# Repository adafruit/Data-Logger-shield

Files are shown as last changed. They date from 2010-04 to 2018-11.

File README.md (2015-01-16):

Adafruit Data Logger Shield PCB
===============================

PCB files for Adafruit's Data Logger Shield for Arduino

For more details, check out the product page at

-----> https://www.adafruit.com/product/1141

Adafruit invests time and resources providing this open source design, 
please support Adafruit and open-source hardware by purchasing 
products from Adafruit!

Designed by Adafruit Industries.  
Creative Commons Attribution, Share-Alike license, check license.txt for more information
All text above must be included in any redistribution

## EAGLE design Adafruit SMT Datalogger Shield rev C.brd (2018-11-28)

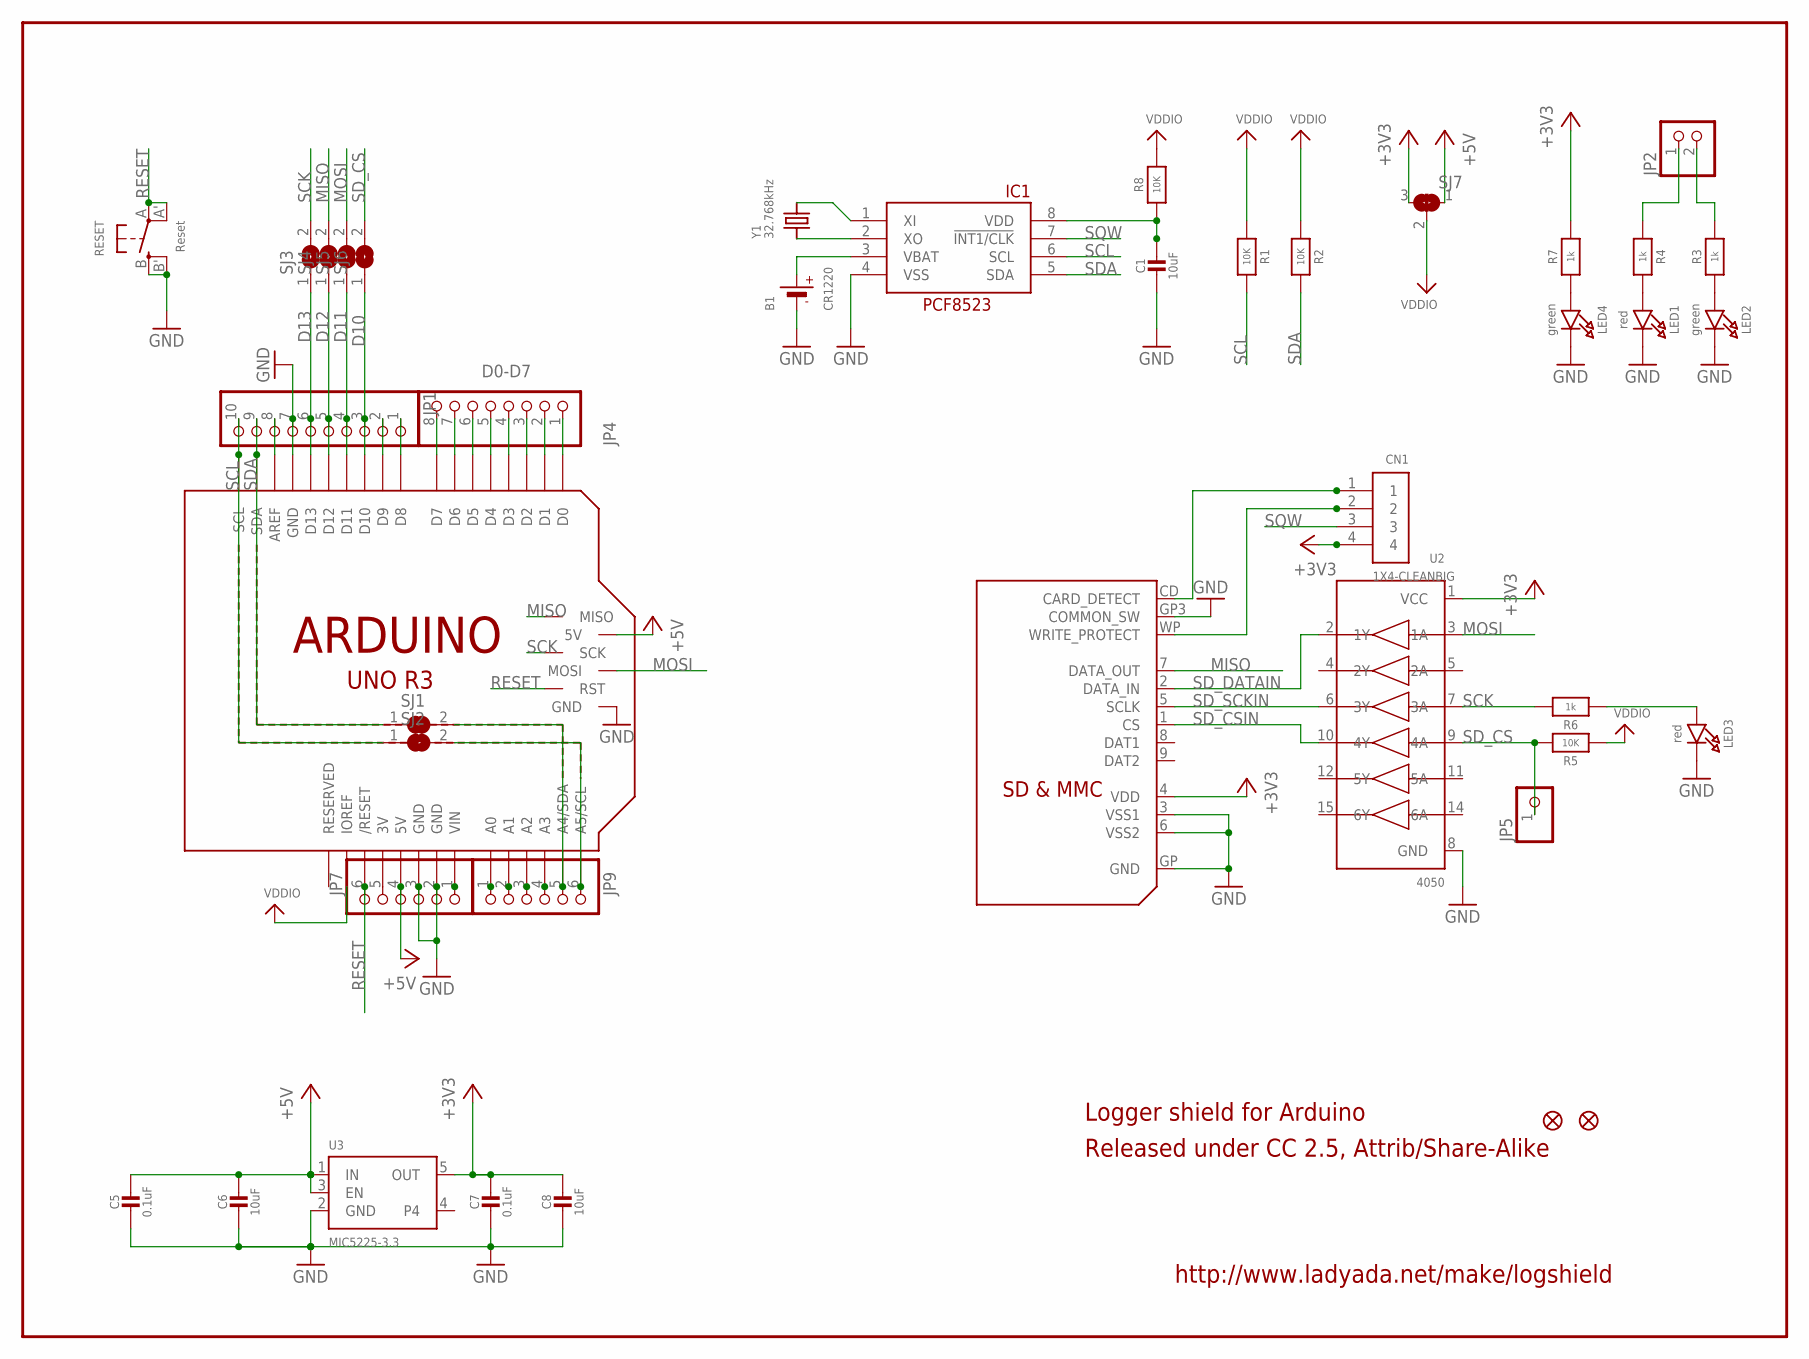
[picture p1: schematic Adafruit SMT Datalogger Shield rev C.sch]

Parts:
B1: CR1220
C1, C6, C8: 10uF; 0805-NO
C5, C7: 0.1uF; 0805-NO
CN1: 1X4-CLEANBIG; 1X04-CLEANBIG
FID1, FID3: FIDUCIAL_1MM
IC1: PCF8523T; SOIC8_150MIL
JP1: HEADER-1X1070MIL; 1X10_ROUND70
JP2: HEADER-1X2ROUND; 1X02_ROUND
JP4: D0-D7; 1X08-BIG
JP5: HEADER-1X1ROUND; 1X01_ROUND
JP7, JP9: PINHD-1X6B; 1X06-BIG
LED1, LED3: red; CHIPLED_0805_NOOUTLINE
LED2, LED4: green; CHIPLED_0805_NOOUTLINE
M1: ARDUINO_R3_ICSP_NODIM; ARDUINOR3_ICSP_NODIM
R1, R2, R5, R8: 10K; 0805-NO
R3, R4, R6, R7: 1k; 0805-NO
RESET: Reset; EVQ-Q2_SMALLER
SJ1, SJ2, SJ3, SJ4, SJ5: SOLDERJUMPER; SOLDERJUMPER_ARROW_NOPASTE
SJ6: SOLDERJUMPERCLOSED; SOLDERJUMPER_CLOSEDWIRE
SJ7: SOLDERJUMPER_2WAY; SOLDERJUMPER_2WAY_OPEN_NOPASTE
U2: 4050; SOIC16
U3: MIC5225-3.3; SOT23-5
U$2: SDMMC06132; 06132
Y1: 32.768kHz; CRYSTAL_8X3.8

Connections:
3.3V: JP7.5, M1.3V
+3V3: C7.1, C8.1, CN1.4, R7.2, SJ7.3, U2.1 (VCC), U3.5 (OUT), U$2.4 (VDD)
+5V: C5.1, C6.1, JP7.4, M1.5V, M1.5V_ICSP (5V), SJ7.1, U3.1 (IN), U3.3 (EN)
A4: JP9.5, M1.A4 (A4/SDA), SJ1.2
A5: JP9.6, M1.A5 (A5/SCL), SJ2.2
D10: JP1.3, M1.D10, SJ6.1
D11: JP1.4, M1.D11, SJ5.1
D12: JP1.5, M1.D12, SJ4.1
D13: JP1.6, M1.D13, SJ3.1
GND: B1.-, C1.2, C5.2, C6.2, C7.2, C8.2, IC1.4 (VSS), JP1.7, JP7.2, JP7.3, LED1.C, LED2.C, LED3.C, LED4.C, M1.GND, M1.GND@1 (GND), M1.GND@2 (GND), M1.GND@3 (GND), RESET.B (S), RESET.B' (S1), U2.8 (GND), U3.2 (GND), U$2.3 (VSS1), U$2.6 (VSS2), U$2.GP (GND), U$2.GP3 (COMMON_SW)
MISO: M1.MISO, SJ4.2, U$2.7 (DATA_OUT)
MOSI: M1.MOSI, SJ5.2, U2.3 (1A)
unnamed: LED1.A, R4.2
unnamed: IC1.2 (XO), Y1.P$1 (1)
unnamed: IC1.1 (XI), Y1.P$4 (2)
unnamed: LED2.A, R3.1
unnamed: LED3.A, R6.1
unnamed: C1.1, IC1.8 (VDD), R8.1
unnamed: JP7.1, M1.VIN
unnamed: JP2.2, R3.2
unnamed: JP2.1, R4.1
unnamed: JP4.1, M1.D0
unnamed: JP4.2, M1.D1
unnamed: JP4.3, M1.D2
unnamed: JP4.4, M1.D3
unnamed: JP4.5, M1.D4
unnamed: JP4.6, M1.D5
unnamed: JP4.7, M1.D6
unnamed: JP4.8, M1.D7
unnamed: JP1.8, M1.AREF
unnamed: JP1.2, M1.D9
unnamed: JP1.1, M1.D8
unnamed: LED4.A, R7.1
unnamed: JP9.1, M1.A0
unnamed: JP9.2, M1.A1
unnamed: JP9.3, M1.A2
unnamed: JP9.4, M1.A3
RESET: JP7.6, M1.RESET (/RESET), M1.RESET_ICSP (RST), RESET.A, RESET.A' (P1)
SCK: M1.SCK, R6.2, SJ3.2, U2.7 (3A)
SCL: IC1.6 (SCL), JP1.10, M1.SCL, R1.2, SJ2.1
SDA: IC1.5 (SDA), JP1.9, M1.SDA, R2.2, SJ1.1
SD_CD: CN1.1, U$2.CD (CARD_DETECT)
SD_CS: JP5.1, R5.2, SJ6.2, U2.9 (4A)
SD_CSIN: U2.10 (4Y), U$2.1 (CS)
SD_DATAIN: U2.2 (1Y), U$2.2 (DATA_IN)
SD_SCKIN: U2.6 (3Y), U$2.5 (SCLK)
SD_WP: CN1.2, U$2.WP (WRITE_PROTECT)
SQW: CN1.3, IC1.7 (!INT1/CLK)
VBAT: B1.+$1 (+), B1.+$2 (+), IC1.3 (VBAT)
VDDIO: M1.IOREF, R1.1, R2.1, R5.1, R8.2, SJ7.2

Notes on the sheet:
http://www.ladyada.net/make/logshield
Released under CC 2.5, Attrib/Share-Alike
Logger shield for Arduino

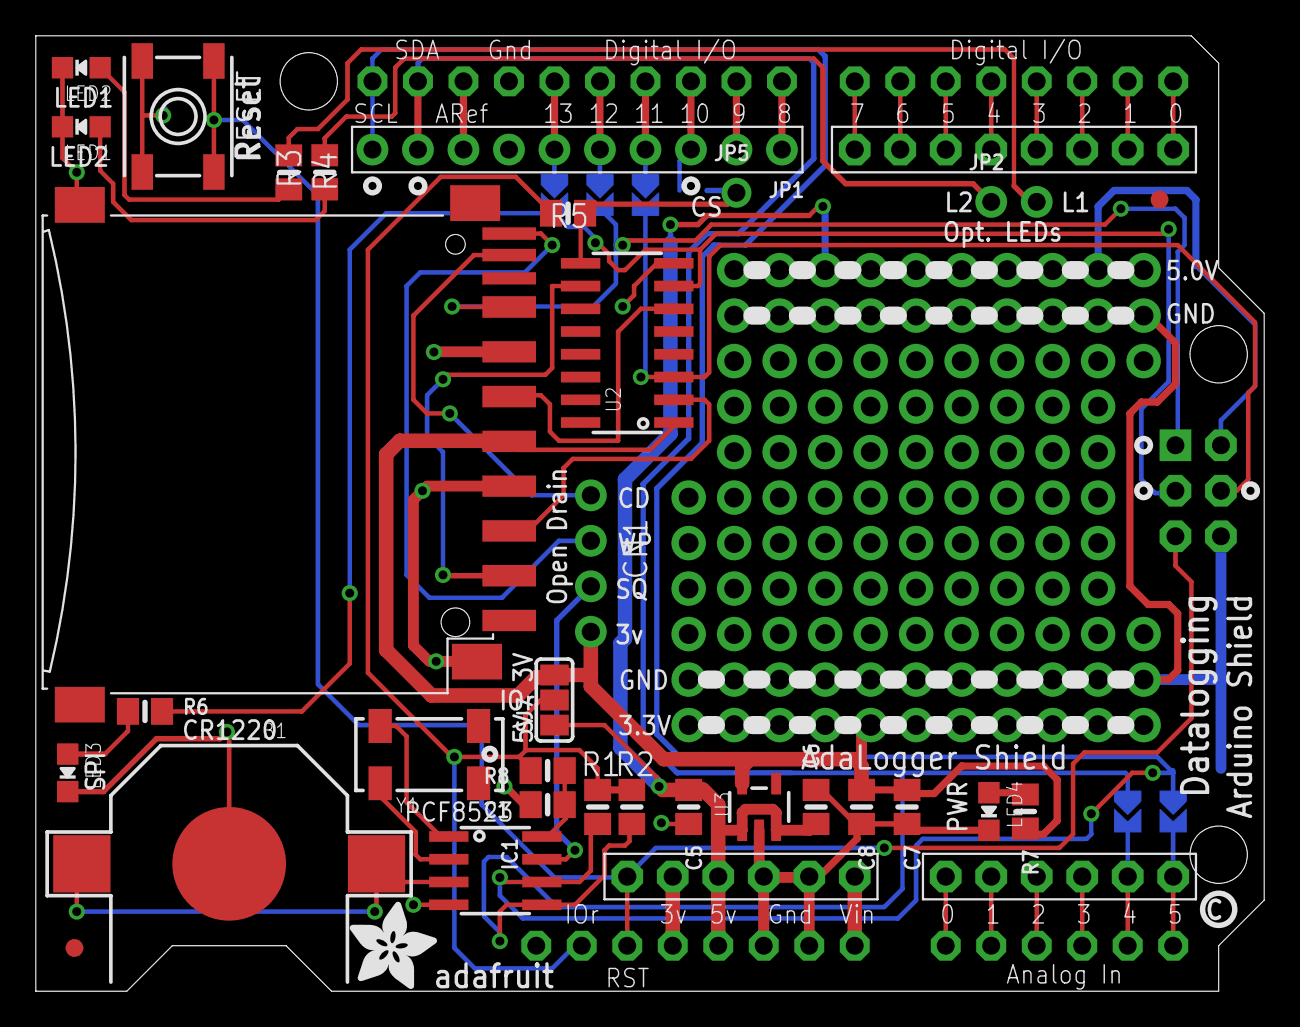
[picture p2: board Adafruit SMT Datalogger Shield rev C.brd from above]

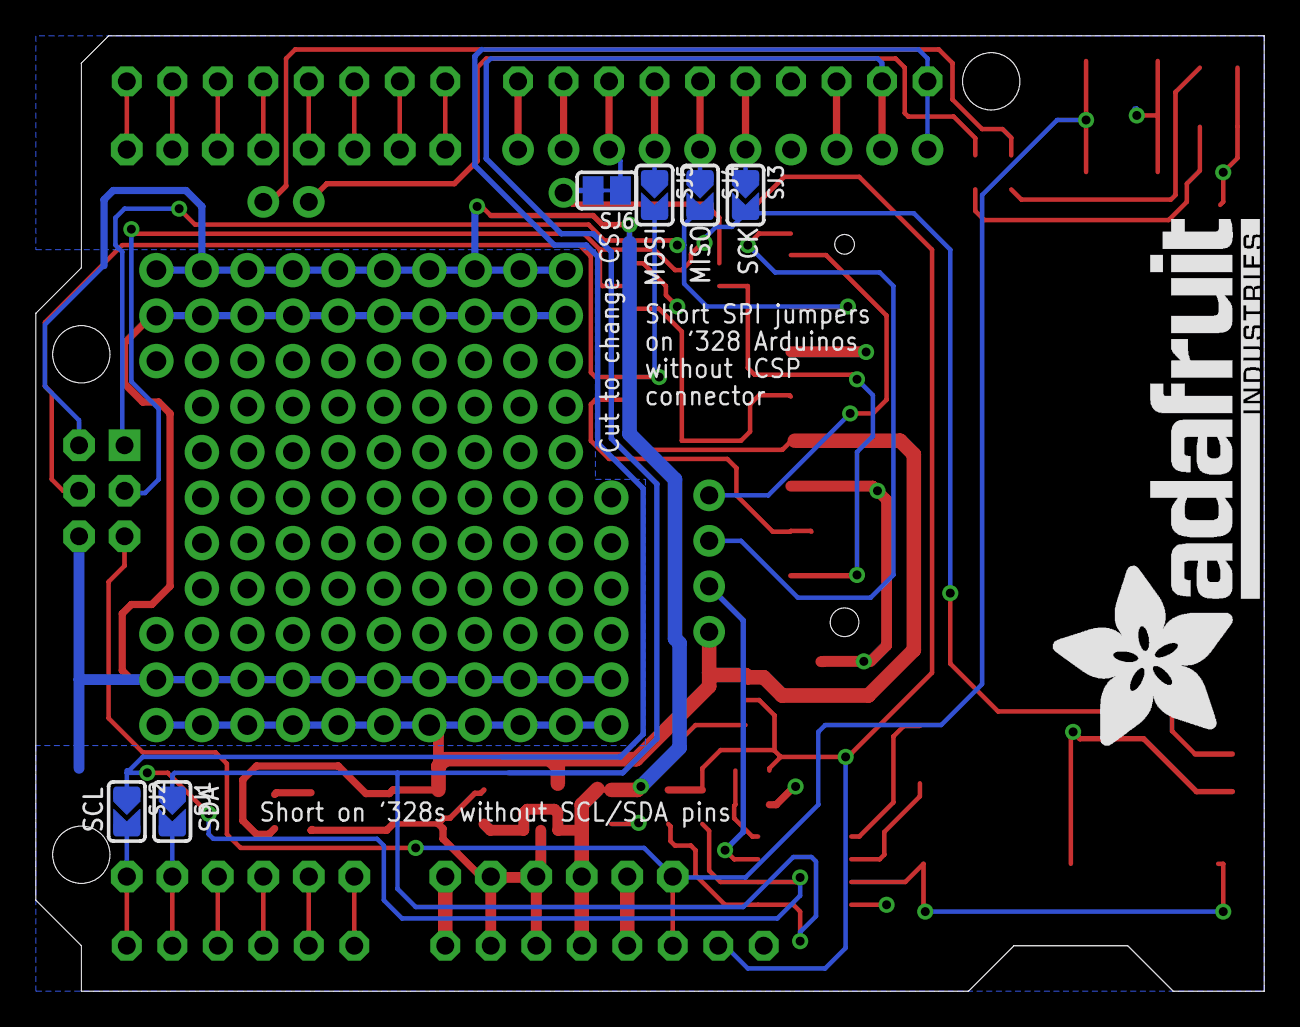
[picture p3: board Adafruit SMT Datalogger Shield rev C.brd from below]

Board: 2 copper layers, 68.6 x 53.3 mm, 44 parts (7 on the bottom side), 50 nets.

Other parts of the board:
U$1: ADAFRUIT_TEXT_30MM
U$3: PCBFEAT-REV-040
U$5: ADAFRUIT_5MM

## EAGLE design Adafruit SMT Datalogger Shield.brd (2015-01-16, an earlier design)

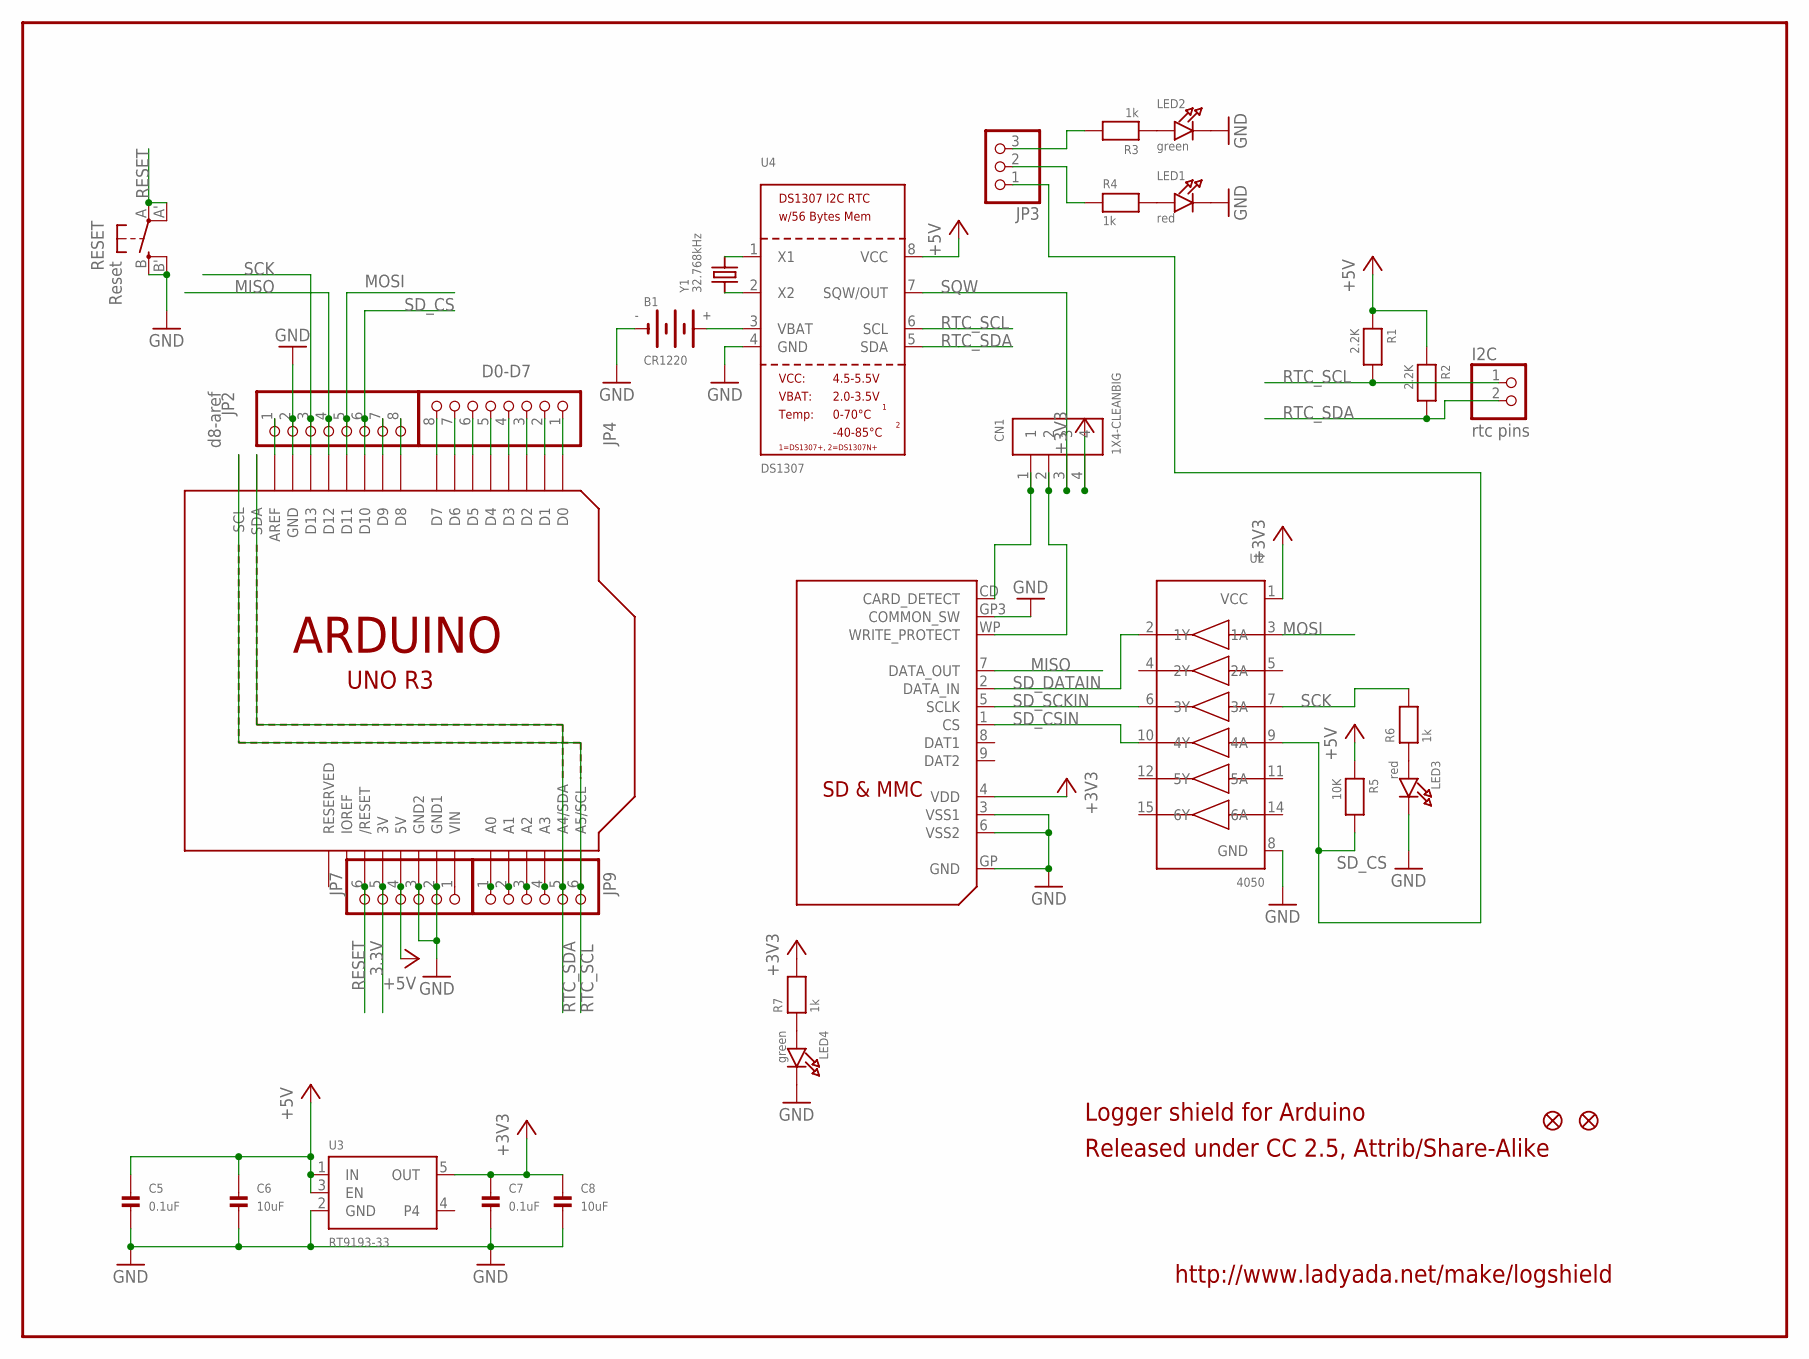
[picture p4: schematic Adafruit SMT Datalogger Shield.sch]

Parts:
B1: CR1220
C5, C7: 0.1uF; 0805
C6, C8: 10uF; 0805
CN1: 1X4-CLEANBIG; 1X04-CLEANBIG
FID1, FID3: FIDUCIAL1X2.5; FIDUCIAL-1X2.5
I2C: rtc pins; 1X02
JP2: d8-aref; 1X08-BIG
JP3: HEADER-1X3ROUND; 1X03_ROUND
JP4: D0-D7; 1X08-BIG
JP7, JP9: PINHD-1X6B; 1X06-BIG
LED1, LED3: red; CHIPLED_0805
LED2, LED4: green; CHIPLED_0805
R1, R2: 2.2K; 0805
R3, R4, R6, R7: 1k; 0805
R5: 10K; 0805
RESET: Reset; EVQ-Q2
U1: ARDUINOR3-DIMENSION; ARDUINOR3
U2: 4050; SOIC16
U3: RT9193-33; SOT23-5
U4: DS1307; SOIC8_150MIL
U$2: SDMMC06132; 06132
Y1: 32.768kHz; CRYSTAL_8X3.8

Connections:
3.3V: JP7.5, U1.3V
+3V3: C7.1, C8.1, CN1.4, R7.2, U2.1 (VCC), U3.5 (OUT), U$2.4 (VDD)
+5V: C5.1, C6.1, JP7.4, R1.1, R2.1, R5.1, U1.5V, U3.1 (IN), U3.3 (EN), U4.8 (VCC)
GND: B1.-, C5.2, C6.2, C7.2, C8.2, JP2.2, JP7.2, JP7.3, LED1.C, LED2.C, LED3.C, LED4.C, RESET.B (S), RESET.B' (S1), U1.GND, U1.GND1, U1.GND2, U2.8 (GND), U3.2 (GND), U4.4 (GND), U$2.3 (VSS1), U$2.6 (VSS2), U$2.GP (GND), U$2.GP3 (COMMON_SW)
MISO: JP2.4, U1.D12, U$2.7 (DATA_OUT)
MOSI: JP2.5, U1.D11, U2.3 (1A)
unnamed: LED1.A, R4.2
unnamed: U4.2 (X2), Y1.P$1 (1)
unnamed: U4.1 (X1), Y1.P$4 (2)
unnamed: LED2.A, R3.1
unnamed: LED3.A, R6.1
unnamed: B1.+$1 (+), U4.3 (VBAT)
unnamed: JP7.1, U1.VIN
unnamed: JP3.3, R3.2
unnamed: JP3.2, R4.1
unnamed: JP4.1, U1.D0
unnamed: JP4.2, U1.D1
unnamed: JP4.3, U1.D2
unnamed: JP4.4, U1.D3
unnamed: JP4.5, U1.D4
unnamed: JP4.6, U1.D5
unnamed: JP4.7, U1.D6
unnamed: JP4.8, U1.D7
unnamed: JP2.1, U1.AREF
unnamed: JP2.7, U1.D9
unnamed: JP2.8, U1.D8
unnamed: LED4.A, R7.1
unnamed: JP9.1, U1.A0
unnamed: JP9.2, U1.A1
unnamed: JP9.3, U1.A2
unnamed: JP9.4, U1.A3
RESET: JP7.6, RESET.A, RESET.A' (P1), U1.RESET (/RESET)
RTC_SCL: I2C.1, JP9.6, R1.2, U1.A5 (A5/SCL), U1.SCL, U4.6 (SCL)
RTC_SDA: I2C.2, JP9.5, R2.2, U1.A4 (A4/SDA), U1.SDA, U4.5 (SDA)
SCK: JP2.3, R6.2, U1.D13, U2.7 (3A)
SD_CD: CN1.1, U$2.CD (CARD_DETECT)
SD_CS: JP2.6, JP3.1, R5.2, U1.D10, U2.9 (4A)
SD_CSIN: U2.10 (4Y), U$2.1 (CS)
SD_DATAIN: U2.2 (1Y), U$2.2 (DATA_IN)
SD_SCKIN: U2.6 (3Y), U$2.5 (SCLK)
SD_WP: CN1.2, U$2.WP (WRITE_PROTECT)
SQW: CN1.3, U4.7 (SQW/OUT)

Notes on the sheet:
http://www.ladyada.net/make/logshield
Released under CC 2.5, Attrib/Share-Alike
Logger shield for Arduino

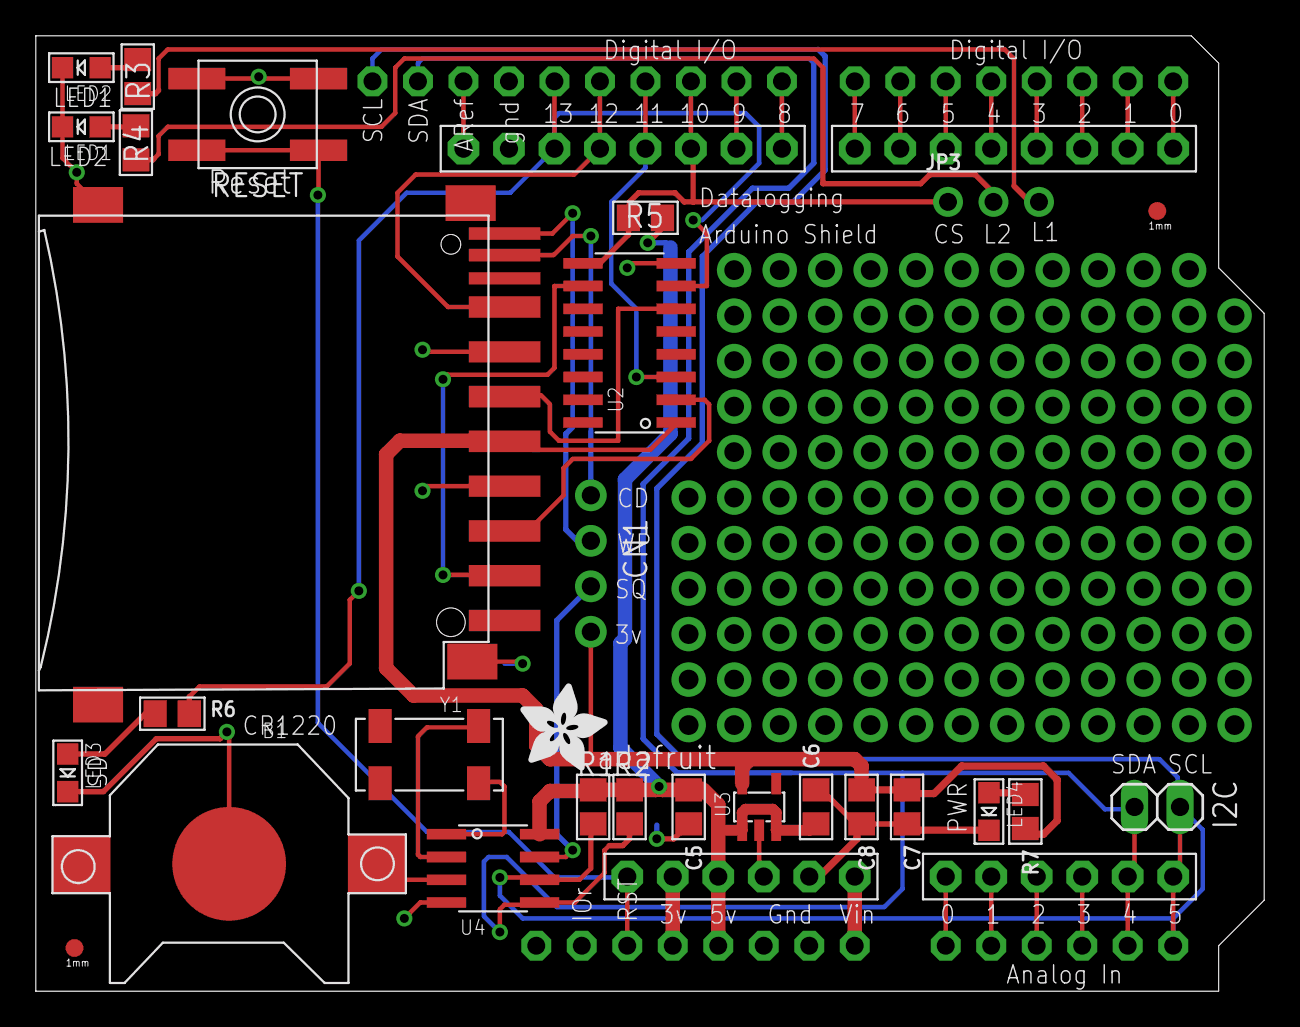
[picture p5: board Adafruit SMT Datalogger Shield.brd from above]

Board: 2 copper layers, 68.6 x 53.3 mm, 34 parts (1 on the bottom side), 42 nets.

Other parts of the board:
U$1: ADAFRUIT_TEXT_30MM
U$5: ADAFRUIT_5MM

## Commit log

2010-04-13 First commit (of v1)
    [logger v1.0.brd, logger v1.0.sch]
2010-04-13 updated parts to adafruit library
    [logger v1.0.brd, logger v1.0.sch]
2015-01-16 updated with the SMT files too!
    [Adafruit Datalogger Shield.brd, Adafruit Datalogger Shield.sch, Adafruit SMT Datalogger Shield.brd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]
2018-11-27 rename and add latest!
    [Adafruit SMT Datalogger Shield rev B.brd, Adafruit SMT Datalogger Shield rev B.sch, Adafruit SMT Datalogger Shield rev C.brd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]
